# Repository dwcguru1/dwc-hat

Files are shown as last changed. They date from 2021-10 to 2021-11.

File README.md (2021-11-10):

# Rasperry Pi - DWC HAT

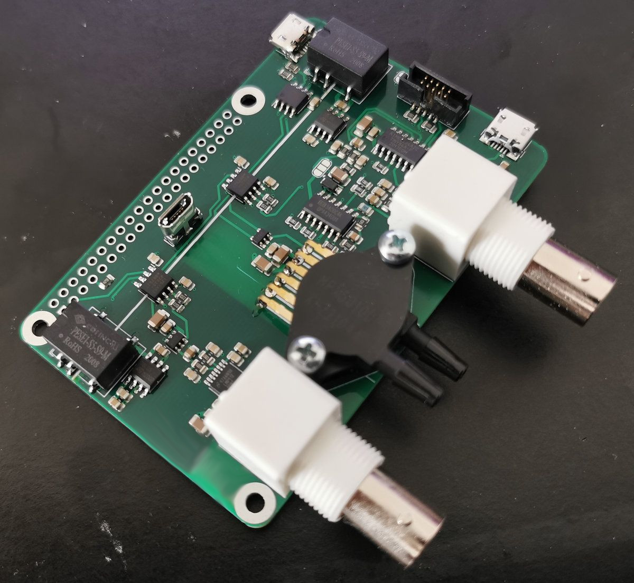
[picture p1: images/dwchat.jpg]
DWC-Hat


Picture above shows V3.0 - New version has some changes (e.g. pinheaders for I2C and 1-wire):

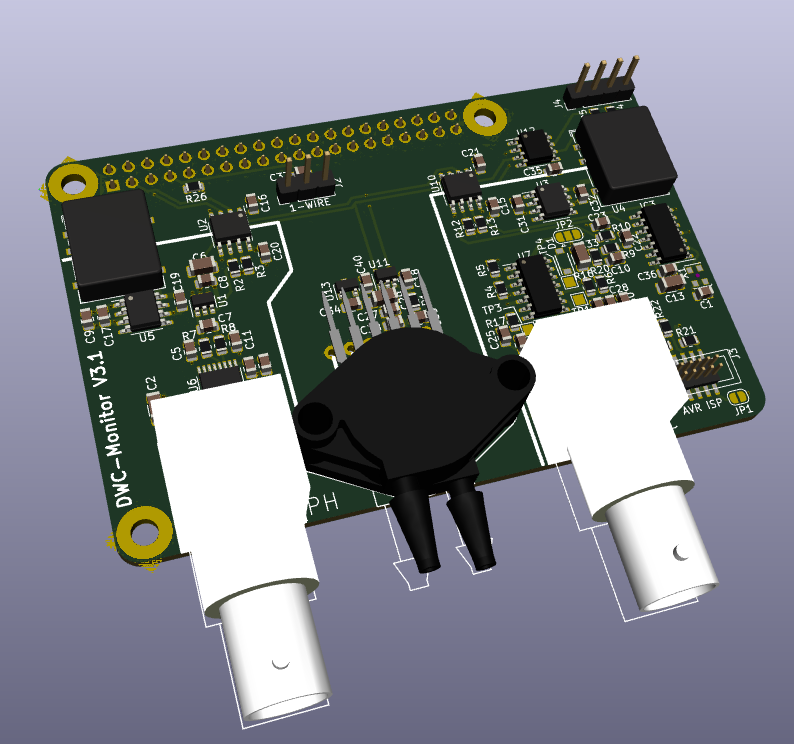
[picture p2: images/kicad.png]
DWC-Hat V3.1


The DWC Hat does following:

- PH measurement (DWC)
- EC measurement (DWC)
- Temperature measurement and correction (DWC)
- Pressure* measurement for water level monitoring (DWC)
- Temperature and humidity measurement of air

*: Everything except the pressure sensing works as expected. It works electrically, but there would be needed a much more sophisticated temperature compensation. To sum it up: It never worked well.

## Raspberry prerequisites

Use `raspi-config` to enable I2C and 1-Wire.

There is a special quirk needed for getting the I2C working properly (because the Pi can't do clock-stretching):

In `/boot/config.txt`:

```
# Uncomment some or all of these to enable the optional hardware interfaces
dtparam=i2c_baudrate=10000
```

It hurts a bit to reduce the I2C rate to 10kHz - but it doesn't really matter :shrug:

Also, the 1-wire pin needs to be configured:
```
# select 1-wire pin
dtoverlay=w1-gpio,gpiopin=4,pullup=on
```

## I2C and 1-wire Devices

There are four I2C and one 1-wire device.

### I2C

```
i2cdetect -y 1:

     0  1  2  3  4  5  6  7  8  9  a  b  c  d  e  f
00:          -- -- -- -- -- -- -- -- -- -- -- -- -- 
10: 10 -- -- -- -- -- -- -- -- -- -- -- -- -- -- -- 
20: -- -- -- -- -- -- -- -- -- -- -- -- -- -- -- -- 
30: -- -- -- -- -- -- -- -- -- -- -- -- -- -- -- -- 
40: 40 -- -- -- -- -- -- -- -- -- -- -- -- 4d -- -- 
50: -- -- -- -- -- -- -- -- -- -- -- -- -- -- -- -- 
60: -- -- -- -- -- -- -- -- -- -- 6a -- -- -- -- -- 
70: -- -- -- -- -- -- -- -- 
```

0x10: EC measurement (fixed by AVR firmware)
0x40: SI7021 temperature and humidity sensor
0x4d: MPX2050DP pressure sensor (ADC MCP3221)
0x6a: PH measurement (ADC MCP3421)

The addresses can differ (e.g. the ADC used in the PH measurement could be either of 0x68 to 0x6f). 

Please check the datasheets of the parts mentioned above and/or `i2cdetect` for the address of your part.

The values are inserted into the `config.ini`:
```
[i2c]
# i2c address of EC measuring (always 0x10)
i2c_ec = 0x10

# i2c address of PH measuring
i2c_ph = 0x6a

# i2c address of MPX2050DP
i2c_pressure = 0x4d

# i2c address of SI7021
i2c_ht = 0x40
```

# 1-Wire

After connecting the 1-wire sensor, there should appear a new device at `/sys/bus/w1/devices/`. 

Add the name to the `config.ini`:

```
[1wire]
ds18b20 = "28-0120625ed8f9"
```

## AVR firmware

The EC-measuring part uses an AVR. Before doing measurements, it needs to be flashed with the firmware.

The ISP connector is 2x10 with 1.27mm pitch. The pinout is compatible to the USBASP.

Also the Makefile expects the USBASP as programmer.

For compilation, you'll need:

```
sudo apt install gcc-avr avrdude avr-libc
```

After that, first initialize the AVR-flags once with:
```
make fuse
```

Afterwards you can compile and flash the AVR with:
```
make
make flash
```

Now, it should be ready to go :slight_smile:

## Calibration

There are two parts that need calibration. (See usage how to get the raw-values).

### PH calibration

PH calibration is done by setting up two reference solutions with PH of 4.01 and 6.86.

After measuring the raw-values, insert them into the `config.ini`:
```
[ph]
# measured PH (raw values)
PH_401 =  13010.0
PH_686 =  2400.0
```

### EC calibration

For calibrating the EC part, two resistors are needed.

They are simply connected to the BNC jack for the EC probe (without the probe) and the raw-values measured by the EC measuring circuit is used for calculating the EC.

The resistors are  390R and 1k.

The values have to be inserted into the `config.ini`:
```
[ec]
# measured EC (raw values)
EC_ADC_390R = 439.0
EC_ADC_1K = 208.0
```

## Usage

By default, the python code does a single measurement and transmitts the date to InfluxDB.

To run it in a loop simply start it in a `screen` session with:
```
 while ((1)); do python3 read.py | tee -a measurements.log ; sleep 1; done

time=1635402997671, ec_raw=243.3764705882353, ec=1345.546146, ph_raw=6772, ph=5.685617, temp=20.875000, pressure_raw=122.5625, pressure_comp=44.20985378262856, humidity=68.68032836914062, airtemp=22.873859863281247
...
```

### Grafana and InfluxDB

Follow any tutorial for installing InfluxDB and Grafana.

Default Database, User, Password is in the `config.ini`.

Make sure to configure the timezone right on the Raspi.

## TODO

There are some things I would like to improve:

- STM32 (M4) for EC measurement. Use internal DAC for DDS sine generation and FIR band pass. This would reduce the parts needed by a lot. Also would improve resolution (12Bit ADC instead of 10Bit ADC).
- Better pt1000 based temperature sensor for DWC. DS18B20 digitizes too coarse what affects temperature compensation of EC negatively.
- Replace the pressure sensing with something else better working. E.g. capacitive sensing with conductive strips glued on the outside of the DWC bin or something else ...

## Disclaimer

Use everything on your own risk!

The project is at it is and if I don't need something else, I won't touch it ever again.

Feel free to do with it whatever you like :slight_smile:

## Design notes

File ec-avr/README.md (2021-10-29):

## compiling the code

For compiling and flashing, you need:
```
sudo apt install gcc-avr avr-libc avrdude
```

After compile with:
```
make
```

If you are using a new AVR, you first have to flash the fuse for the correct oscillator settings:
```
make fuse
```

Afterwards, flash the `.hex`-file.

```
make flash
```

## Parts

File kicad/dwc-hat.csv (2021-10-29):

Reference | Value | Footprint | Datasheet | Distributor | Manufacturer | OrderNr
P1 | BNC | myfootprints:BNC_UG_1094W1 |  | D | 1-1337543-0 | A97553-ND
C12 | 100n | Capacitor_SMD:C_0805_2012Metric
P4 | BNC | myfootprints:BNC_UG_1094W1 |  | D | 1-1337543-0 | A97553-ND
R11 | 3.3k | Resistor_SMD:R_0805_2012Metric
D1 | BAT54T1G | Diodes_SMD:SOD-123 |  | D | BAT54T1G | BAT54T1GOSDKR-ND
C33 | 10µ | Capacitor_SMD:C_1206_3216Metric
R20 | 10k | Resistor_SMD:R_0805_2012Metric
U7 | OPA4340 | Package_SO:SO-14_3.9x8.65mm_P1.27mm | http://www.ti.com/lit/ds/symlink/tl071.pdf | D | OPA4340UA/2K5 | 296-26286-1-ND
R14 | 5.1k | Resistor_SMD:R_0805_2012Metric
R15 | 20k | Resistor_SMD:R_0805_2012Metric
C25 | 33n | Capacitor_SMD:C_0805_2012Metric
C24 | 22n | Capacitor_SMD:C_0805_2012Metric
R17 | 8.2k | Resistor_SMD:R_0805_2012Metric
IC3 | ATTINY84A-SS | Package_SO:SO-14_3.9x8.65mm_P1.27mm |  | D | ATTINY84A-SSF | ATTINY84A-SSF-ND
R22 | 10k | Resistor_SMD:R_0805_2012Metric
C32 | 100n/25V | Capacitor_SMD:C_0805_2012Metric
C31 | 100n | Capacitor_SMD:C_0805_2012Metric
C36 | 100n | Capacitor_SMD:C_0805_2012Metric
U6 | LMP91200 | Package_SO:TSSOP-16_4.4x5mm_P0.65mm |  | D | LMP91200MT/NOPB | LMP91200MT/NOPB-ND
U10 | ADUM1251 | Package_SO:SOIC-8_3.9x4.9mm_P1.27mm |  | D | ADUM1251ARZ-RL7 | ADUM1251ARZ-RL7CT-ND
R13 | 2k2 | Resistor_SMD:R_0805_2012Metric
R12 | 2k2 | Resistor_SMD:R_0805_2012Metric
J3 | Conn_02x05_Odd_Even | myfootprints:PinHeader_IDC_2x05_P1.27mm_Vertical_SMD | ~ | D | 3221-10-0300-00 | 1175-1735-ND
JP1 | Jumper_NO_Small | Jumper:SolderJumper-2_P1.3mm_Open_RoundedPad1.0x1.5mm | ~ | -
NT1 | Net-Tie_2 | NetTie:NetTie-2_SMD_Pad0.5mm | ~ | -
NT2 | Net-Tie_2 | NetTie:NetTie-2_SMD_Pad0.5mm | ~ | -
U1 | MCP3421 | Package_TO_SOT_SMD:SOT-23-6 |  | D | MCP3421A2T-E/CH | MCP3421A2T-E/CHCT-ND
U2 | ADUM1251 | Package_SO:SOIC-8_3.9x4.9mm_P1.27mm |  | D | ADUM1251ARZ-RL7 | ADUM1251ARZ-RL7CT-ND
R3 | 2k2 | Resistor_SMD:R_0805_2012Metric
R2 | 2k2 | Resistor_SMD:R_0805_2012Metric
C2 | 10µ | Capacitor_SMD:C_1206_3216Metric | ~
C3 | 1µ | Capacitor_SMD:C_0805_2012Metric | ~
C4 | 100n | Capacitor_SMD:C_0805_2012Metric | ~
C6 | 10µ | Capacitor_SMD:C_1206_3216Metric | ~
C8 | 100n | Capacitor_SMD:C_0805_2012Metric | ~
C9 | 1µ | Capacitor_SMD:C_0805_2012Metric | ~
C13 | 10µ | Capacitor_SMD:C_1206_3216Metric | ~
J1 | Raspberry Pi GPIO | Connector_PinSocket_2.54mm:PinSocket_2x20_P2.54mm_Vertical |  | D | ESQ-120-24-T-D | SAM15592-ND
C14 | 1µ | Capacitor_SMD:C_0805_2012Metric | ~
U4 | 0509 | myfootprints:Converter_DCDC_SMD |  | D | PESE1-S5-S9-M | 102-6308-ND
U3 | L78L05_SO8 | Package_SO:SOIC-8_3.9x4.9mm_P1.27mm | http://www.st.com/content/ccc/resource/technical/document/datasheet/15/55/e5/aa/23/5b/43/fd/CD00000446.pdf/files/CD00000446.pdf/jcr:content/translations/en.CD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 | D | L78L05CD13TR | 497-7267-1-ND
C19 | 100n/25V | Capacitor_SMD:C_0805_2012Metric
C17 | 100n | Capacitor_SMD:C_0805_2012Metric
U8 | 0509 | myfootprints:Converter_DCDC_SMD |  | D | PESE1-S5-S9-M | 102-6308-ND
U5 | L78L05_SO8 | Package_SO:SOIC-8_3.9x4.9mm_P1.27mm | http://www.st.com/content/ccc/resource/technical/document/datasheet/15/55/e5/aa/23/5b/43/fd/CD00000446.pdf/files/CD00000446.pdf/jcr:content/translations/en.CD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 | D | L78L05CD13TR | 497-7267-1-ND
R4 | 100k | Resistor_SMD:R_0805_2012Metric | ~
R5 | 100k | Resistor_SMD:R_0805_2012Metric | ~
R19 | 4.7k | Resistor_SMD:R_0805_2012Metric
R18 | 4.7k | Resistor_SMD:R_0805_2012Metric
C30 | 100n | Capacitor_SMD:C_0805_2012Metric
C28 | 100n | Capacitor_SMD:C_0805_2012Metric
C26 | 1µ | Capacitor_SMD:C_0805_2012Metric
R16 | 100k | Resistor_SMD:R_0805_2012Metric
R6 | 100k | Resistor_SMD:R_0805_2012Metric
C20 | 100n | Capacitor_SMD:C_0805_2012Metric | ~
C21 | 100n | Capacitor_SMD:C_0805_2012Metric | ~
C15 | 100n | Capacitor_SMD:C_0805_2012Metric | ~
C16 | 100n | Capacitor_SMD:C_0805_2012Metric | ~
R7 | 1k | Resistor_SMD:R_0805_2012Metric
R8 | 1k | Resistor_SMD:R_0805_2012Metric
C7 | 47n | Capacitor_SMD:C_0805_2012Metric
C5 | 100n | Capacitor_SMD:C_0805_2012Metric
C11 | 100n | Capacitor_SMD:C_0805_2012Metric
JP2 | Jumper_3_Open | Jumper:SolderJumper-3_P1.3mm_Open_RoundedPad1.0x1.5mm | ~ | -
R9 | 1k | Resistor_SMD:R_0805_2012Metric
R10 | 1k | Resistor_SMD:R_0805_2012Metric
C22 | 47n | Capacitor_SMD:C_0805_2012Metric
C10 | 100n | Capacitor_SMD:C_0805_2012Metric
C23 | 100n | Capacitor_SMD:C_0805_2012Metric
R21 | 1k | Resistor_SMD:R_0805_2012Metric
R23 | 1k | Resistor_SMD:R_0805_2012Metric
U9 | MPX5010DP | myfootprints:MPX5010DP |  | D | MPX5010DP | MPX5010DP-ND
C29 | 10µ | Capacitor_SMD:C_1206_3216Metric | ~
C34 | 100n | Capacitor_SMD:C_0805_2012Metric | ~
U11 | MCP3221 | Package_TO_SOT_SMD:SOT-23-5 |  | D | MCP3221A5T-I/OT | MCP3221A5T-I/OTCT-ND
U12 | PCA9515 | Package_SO:SO-8_3.9x4.9mm_P1.27mm |  | D | PI6ULS5V9515AWEX | PI6ULS5V9515AWEXCT-ND
R25 | 2k2 | Resistor_SMD:R_0805_2012Metric
R24 | 2k2 | Resistor_SMD:R_0805_2012Metric
C35 | 100n | Capacitor_SMD:C_0805_2012Metric | ~
R26 | 4.7k | Resistor_SMD:R_0805_2012Metric
C37 | 1µ | Capacitor_SMD:C_0805_2012Metric
C39 | 470p | Capacitor_SMD:C_0805_2012Metric
C27 | 1µ | Capacitor_SMD:C_0805_2012Metric
C38 | 100n | Capacitor_SMD:C_0805_2012Metric
J4 | Conn_01x04 | Connector_PinHeader_2.54mm:PinHeader_1x04_P2.54mm_Vertical | ~
J2 | Conn_01x03 | Connector_PinHeader_2.54mm:PinHeader_1x03_P2.54mm_Vertical | ~
X1 | 8MHz | Oscillator:Oscillator_SMD_EuroQuartz_XO32-4Pin_3.2x2.5mm | http://cdn-reichelt.de/documents/datenblatt/B400/XO32.pdf
C1 | 100n | Capacitor_SMD:C_0805_2012Metric | ~
TP2 | TestPoint | TestPoint:TestPoint_Pad_1.5x1.5mm | ~
TP3 | TestPoint | TestPoint:TestPoint_Pad_1.5x1.5mm | ~
TP1 | TestPoint | TestPoint:TestPoint_Pad_1.5x1.5mm | ~
TP4 | TestPoint | TestPoint:TestPoint_Pad_1.5x1.5mm | ~
R1 | 1k | Resistor_SMD:R_0805_2012Metric
C18 | 100n | Capacitor_SMD:C_0805_2012Metric
U13 | MCP1541-TT | Package_TO_SOT_SMD:SOT-23 | http://ww1.microchip.com/downloads/en/devicedoc/21653b.pdf
C40 | 1µ | Capacitor_SMD:C_0805_2012Metric

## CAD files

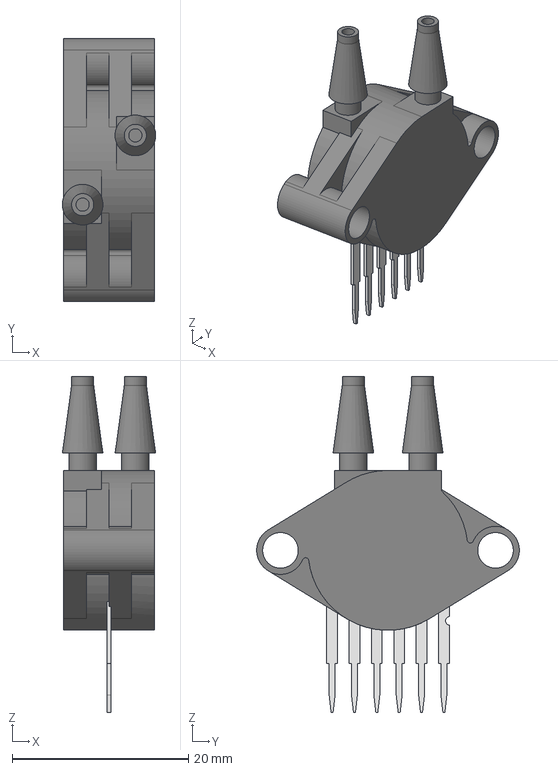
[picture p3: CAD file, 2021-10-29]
kicad/3d/NXP_-_MPX5010DP.step
10.6 x 29.8 x 38.2 mm

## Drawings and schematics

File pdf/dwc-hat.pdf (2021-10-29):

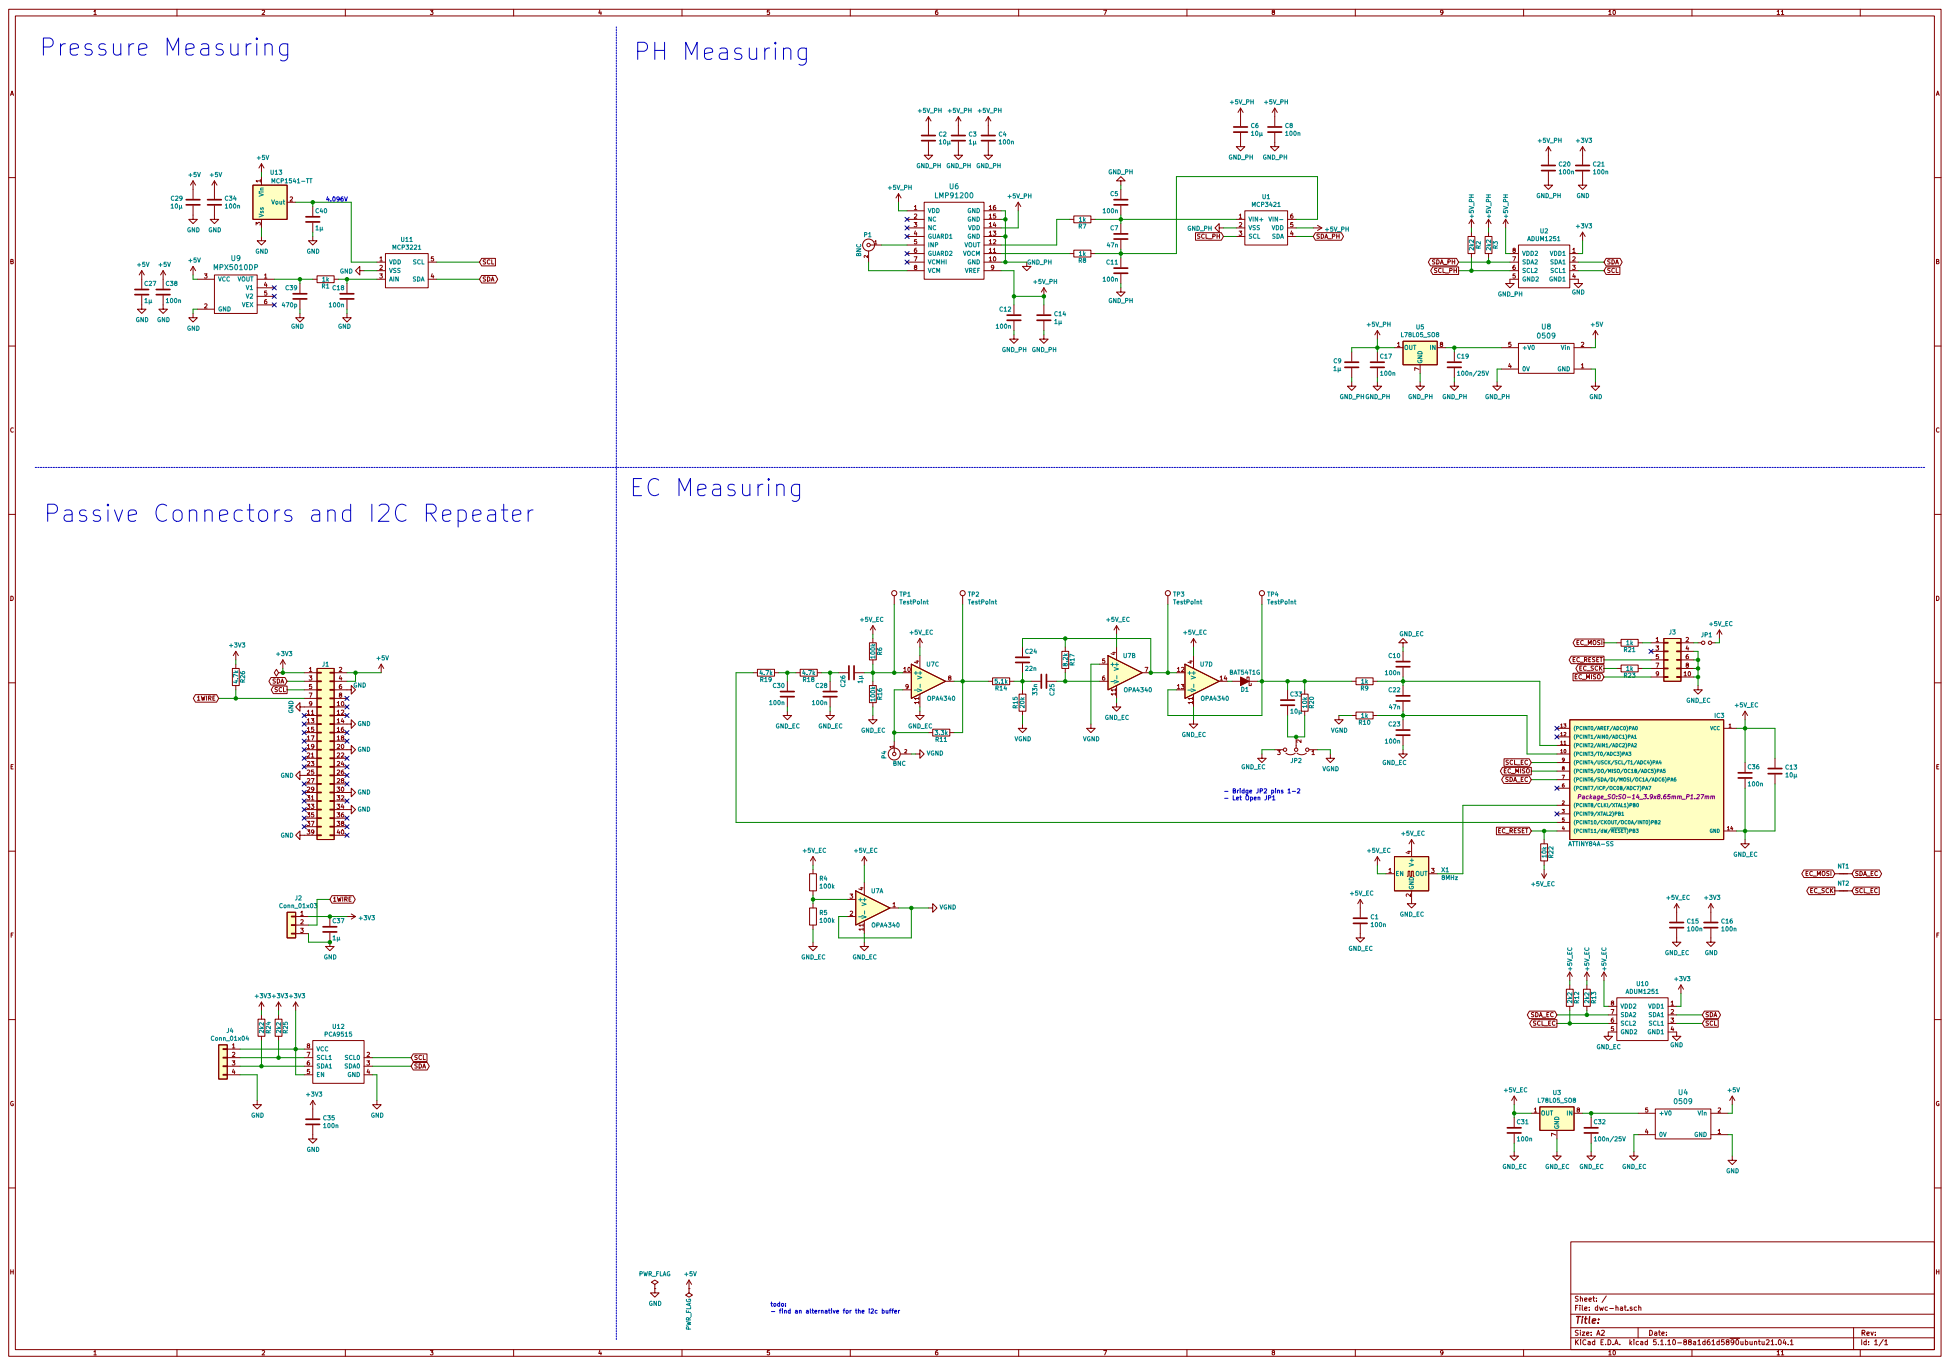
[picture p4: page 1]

1 Vout 2 Vss 3 U13 MCP1541-TT GND
10µ GND

Passive Connectors and I2C Repeater

todo: - find an alternative for the i2c buffer

Id: 1/1 Title: File: dwc-hat.sch Sheet: /

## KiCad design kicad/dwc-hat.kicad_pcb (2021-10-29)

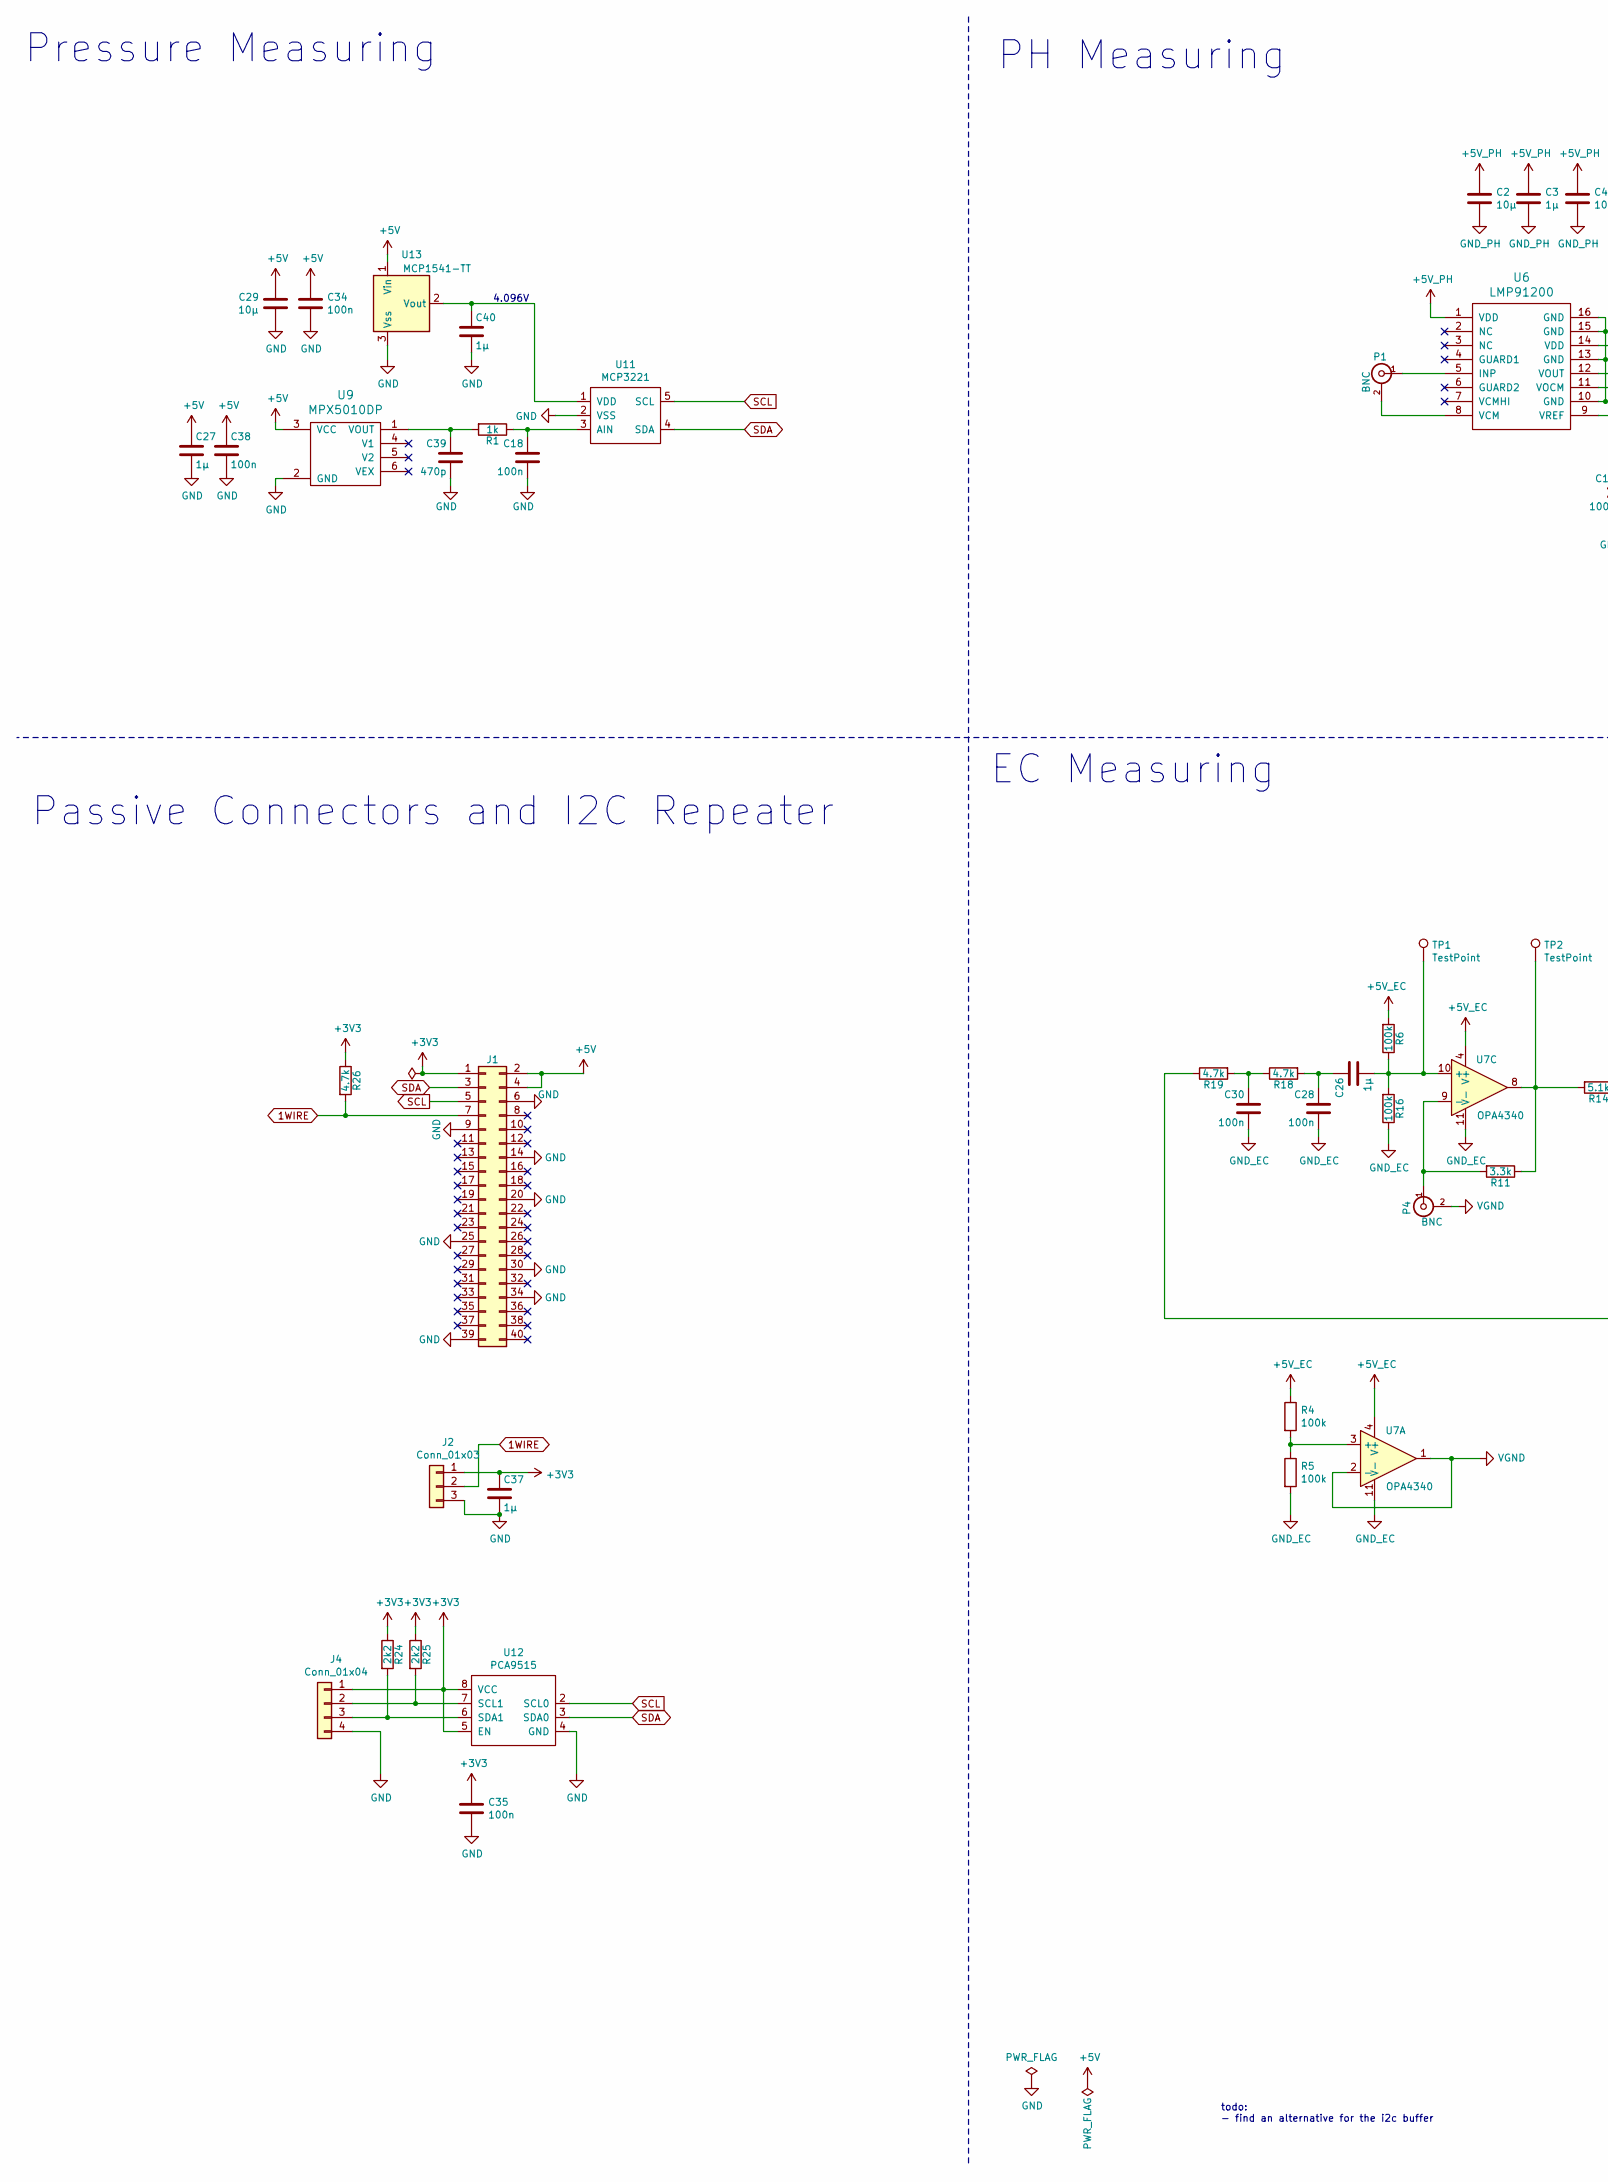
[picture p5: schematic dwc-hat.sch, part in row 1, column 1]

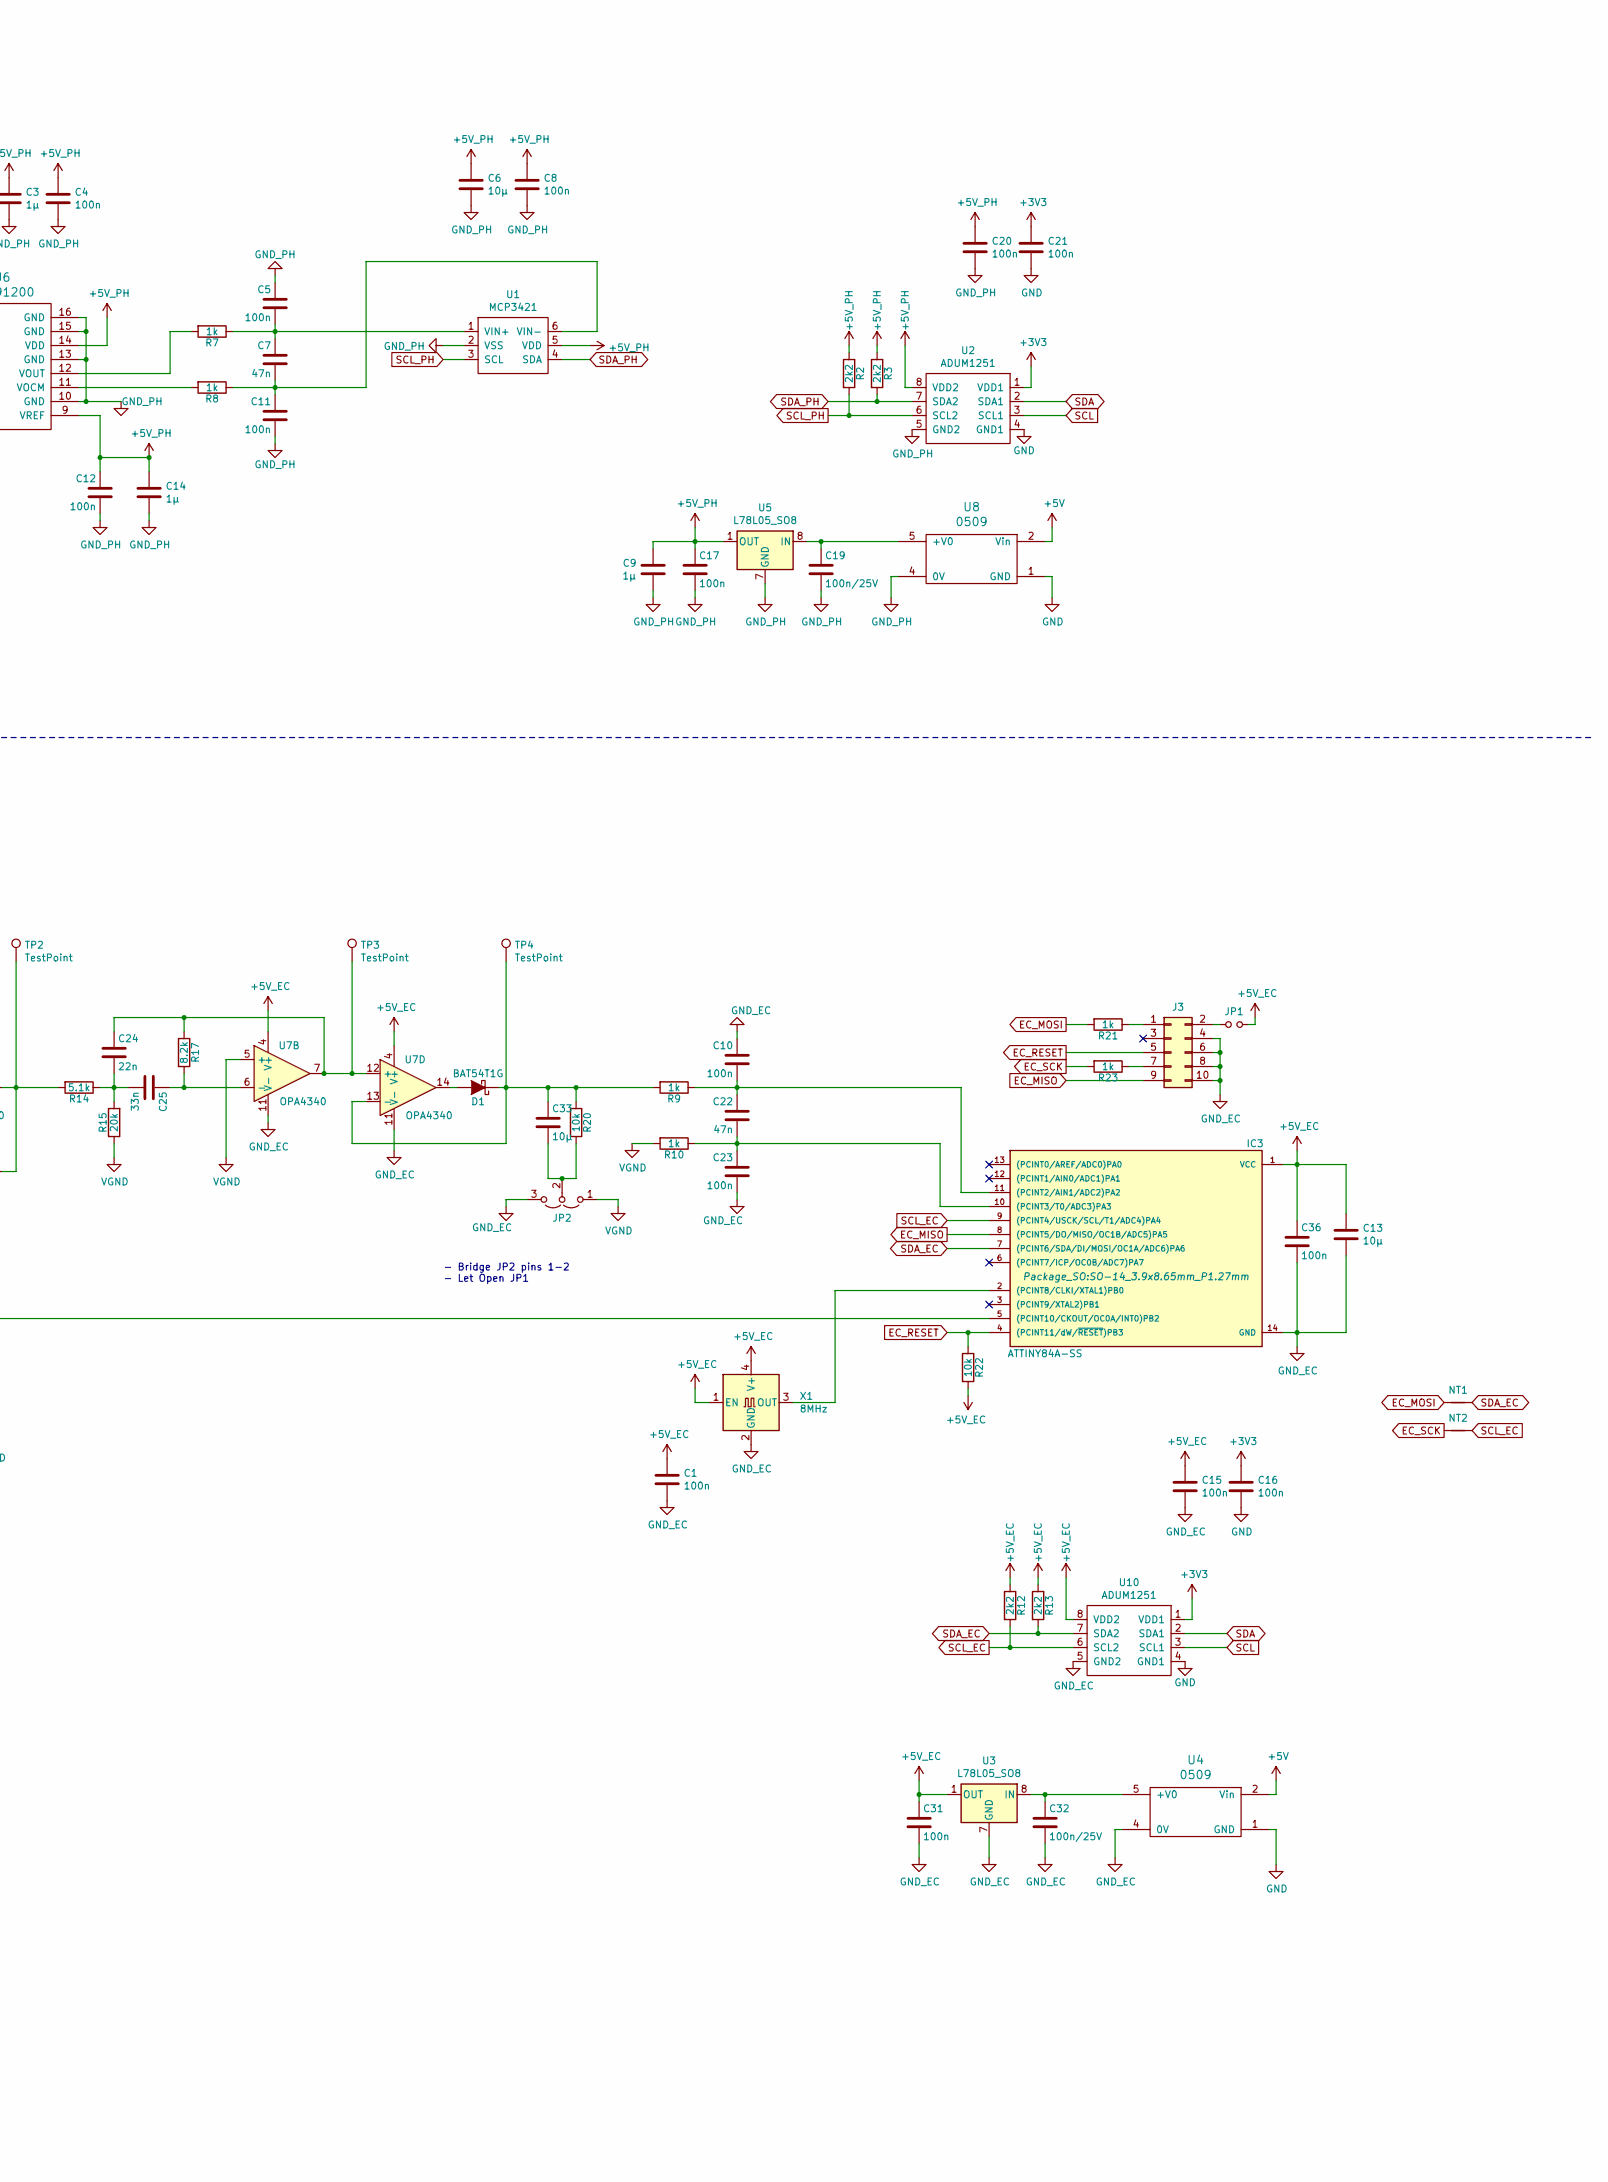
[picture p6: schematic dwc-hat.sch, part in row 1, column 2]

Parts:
C1, C4, C5, C8, C10, C11, C12, C15, C16, C17, C18, C20, C21, C23, C28, C30, C31, C34, C35, C36, C38: 100n; C_0805_2012Metric
C2, C6, C13, C29, C33: 10µ; C_1206_3216Metric
C3, C9, C14, C26, C27, C37, C40: 1µ; C_0805_2012Metric
C7, C22: 47n; C_0805_2012Metric
C19, C32: 100n/25V; C_0805_2012Metric
C24: 22n; C_0805_2012Metric
C25: 33n; C_0805_2012Metric
C39: 470p; C_0805_2012Metric
D1: BAT54T1G; SOD-123
IC3: ATTINY84A-SS; SO-14_3.9x8.65mm_P1.27mm
J1: Raspberry Pi GPIO; PinSocket_2x20_P2.54mm_Vertical
J2: Conn_01x03; PinHeader_1x03_P2.54mm_Vertical
J3: Conn_02x05_Odd_Even; PinHeader_IDC_2x05_P1.27mm_Vertical_SMD
J4: Conn_01x04; PinHeader_1x04_P2.54mm_Vertical
JP1: Jumper_NO_Small; SolderJumper-2_P1.3mm_Open_RoundedPad1.0x1.5mm
JP2: Jumper_3_Open; SolderJumper-3_P1.3mm_Open_RoundedPad1.0x1.5mm
NT1, NT2: Net-Tie_2; NetTie-2_SMD_Pad0.5mm
P1, P4: BNC; BNC_UG_1094W1
R1, R7, R8, R9, R10, R21, R23: 1k; R_0805_2012Metric
R2, R3, R12, R13, R24, R25: 2k2; R_0805_2012Metric
R4, R5, R6, R16: 100k; R_0805_2012Metric
R11: 3.3k; R_0805_2012Metric
R14: 5.1k; R_0805_2012Metric
R15: 20k; R_0805_2012Metric
R17: 8.2k; R_0805_2012Metric
R18, R19, R26: 4.7k; R_0805_2012Metric
R20, R22: 10k; R_0805_2012Metric
TP1, TP2, TP3, TP4: TestPoint; TestPoint_Pad_1.5x1.5mm
U1: MCP3421; SOT-23-6
U2, U10: ADUM1251; SOIC-8_3.9x4.9mm_P1.27mm
U3, U5: L78L05_SO8; SOIC-8_3.9x4.9mm_P1.27mm
U4, U8: 0509; Converter_DCDC_SMD
U6: LMP91200; TSSOP-16_4.4x5mm_P0.65mm
U7: OPA4340; SO-14_3.9x8.65mm_P1.27mm
U9: MPX5010DP
U11: MCP3221; SOT-23-5
U12: PCA9515; SO-8_3.9x4.9mm_P1.27mm
U13: MCP1541-TT; SOT-23
X1: 8MHz; Oscillator_SMD_EuroQuartz_XO32-4Pin_3.2x2.5mm

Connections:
1WIRE: J1.7, J2.2, R26.2
+3V3: C16.1, C21.1, C35.1, C37.1, J1.1, J2.1, J4.1, R24.1, R25.1, R26.1, U2.1 (VDD1), U10.1 (VDD1), U12.5 (EN), U12.8 (VCC)
+5V: C27.1, C29.1, C34.1, C38.1, J1.2, J1.4, U4.2 (Vin), U8.2 (Vin), U9.3 (VCC), U13.1 (Vin)
+5V_EC: C1.1, C13.1, C15.1, C31.1, C36.1, IC3.1 (VCC), JP1.2, R4.1, R6.2, R12.1, R13.1, R22.2, U3.1 (OUT), U7.4 (V+), U10.8 (VDD2), X1.1 (EN), X1.4 (V+)
+5V_PH: C2.1, C3.1, C4.1, C6.1, C8.1, C9.1, C12.1, C14.1, C17.1, C20.1, R2.1, R3.1, U1.5 (VDD), U2.8 (VDD2), U5.1 (OUT), U6.1 (VDD), U6.9 (VREF), U6.14 (VDD)
EC_MISO: IC3.8 ((PCINT5/DO/MISO/OC1B/ADC5)PA5), J3.9
EC_MOSI: NT1.1, R21.2
EC_RESET: IC3.4 ((PCINT11/dW/~RESET~)PB3), J3.5, R22.1
EC_SCK: NT2.1, R23.2
GND: C16.2, C18.2, C21.2, C27.2, C29.2, C34.2, C35.2, C37.2, C38.2, C39.2, C40.2, J1.6, J1.9, J1.14, J1.20, J1.25, J1.30, J1.34, J1.39, J2.3, J4.4, U2.4 (GND1), U4.1 (GND), U8.1 (GND), U9.2 (GND), U10.4 (GND1), U11.2 (VSS), U12.4 (GND), U13.3 (Vss)
GND_EC: C1.2, C10.1, C13.2, C15.2, C23.2, C28.2, C30.2, C31.2, C32.2, C36.2, IC3.14 (GND), J3.4, J3.6, J3.8, J3.10, JP2.3 (B), R5.2, R16.1, U3.2 (GND), U3.3 (GND), U3.6 (GND), U3.7 (GND), U4.4 (0V), U7.11 (V-), U10.5 (GND2), X1.2 (GND)
GND_PH: C2.2, C3.2, C4.2, C5.1, C6.2, C8.2, C9.2, C11.2, C12.2, C14.2, C17.2, C19.2, C20.2, U1.2 (VSS), U2.5 (GND2), U5.2 (GND), U5.3 (GND), U5.6 (GND), U5.7 (GND), U6.10 (GND), U6.13 (GND), U6.15 (GND), U6.16 (GND), U8.4 (0V)
unnamed: C5.2, C7.1, R7.1, U1.1 (VIN+)
unnamed: C10.2, C22.1, IC3.11 ((PCINT2/AIN1/ADC2)PA2), R9.1
unnamed: C7.2, C11.1, R8.1, U1.6 (VIN-)
unnamed: C18.1, R1.1, U11.3 (AIN)
unnamed: C19.1, U5.8 (IN), U8.5 (+V0)
unnamed: C22.2, C23.1, IC3.10 ((PCINT3/T0/ADC3)PA3), R10.1
unnamed: C24.1, R17.1, TP3.1, U7.7, U7.12 (+)
unnamed: C24.2, C25.2, R14.1, R15.2
unnamed: C25.1, R17.2, U7.6 (-)
unnamed: C26.1, C28.1, R18.2
unnamed: C26.2, R6.1, R16.2, TP1.1, U7.10 (+)
unnamed: C30.1, R18.1, R19.2
unnamed: C32.1, U3.8 (IN), U4.5 (+V0)
unnamed: C33.1, D1.1 (K), R9.2, R20.1, TP4.1, U7.13 (-)
unnamed: C33.2, JP2.2 (C), R20.2
unnamed: C39.1, R1.2, U9.1 (VOUT)
unnamed: C40.1, U11.1 (VDD), U13.2 (Vout)
unnamed: D1.2 (A), U7.14
unnamed: IC3.2 ((PCINT8/CLKI/XTAL1)PB0), X1.3 (OUT)
unnamed: IC3.5 ((PCINT10/CKOUT/OC0A/INT0)PB2), R19.1
unnamed: J3.1, R21.1
unnamed: J3.2, JP1.1
unnamed: J3.7, R23.1
unnamed: J4.2, R25.2, U12.7 (SCL1)
unnamed: J4.3, R24.2, U12.6 (SDA1)
unnamed: P1.1 (In), U6.5 (INP)
unnamed: P1.2 (Ext), U6.8 (VCM)
unnamed: P4.1 (In), R11.2, U7.9 (-)
unnamed: R4.2, R5.1, U7.3 (+)
unnamed: R7.2, U6.12 (VOUT)
unnamed: R8.2, U6.11 (VOCM)
unnamed: R11.1, R14.2, TP2.1, U7.8
SCL: J1.5, U2.3 (SCL1), U10.3 (SCL1), U11.5 (SCL), U12.2 (SCL0)
SCL_EC: IC3.9 ((PCINT4/USCK/SCL/T1/ADC4)PA4), NT2.2, R12.2, U10.6 (SCL2)
SCL_PH: R2.2, U1.3 (SCL), U2.6 (SCL2)
SDA: J1.3, U2.2 (SDA1), U10.2 (SDA1), U11.4 (SDA), U12.3 (SDA0)
SDA_EC: IC3.7 ((PCINT6/SDA/DI/MOSI/OC1A/ADC6)PA6), NT1.2, R13.2, U10.7 (SDA2)
SDA_PH: R3.2, U1.4 (SDA), U2.7 (SDA2)
VGND: JP2.1 (A), P4.2 (Ext), R10.2, R15.1, U7.1, U7.2 (-), U7.5 (+)

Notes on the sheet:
todo: - find an alternative for the i2c buffer
EC Measuring
PH Measuring
Pressure Measuring
Passive Connectors and I2C Repeater
- Bridge JP2 pins 1-2 - Let Open JP1
4.096V

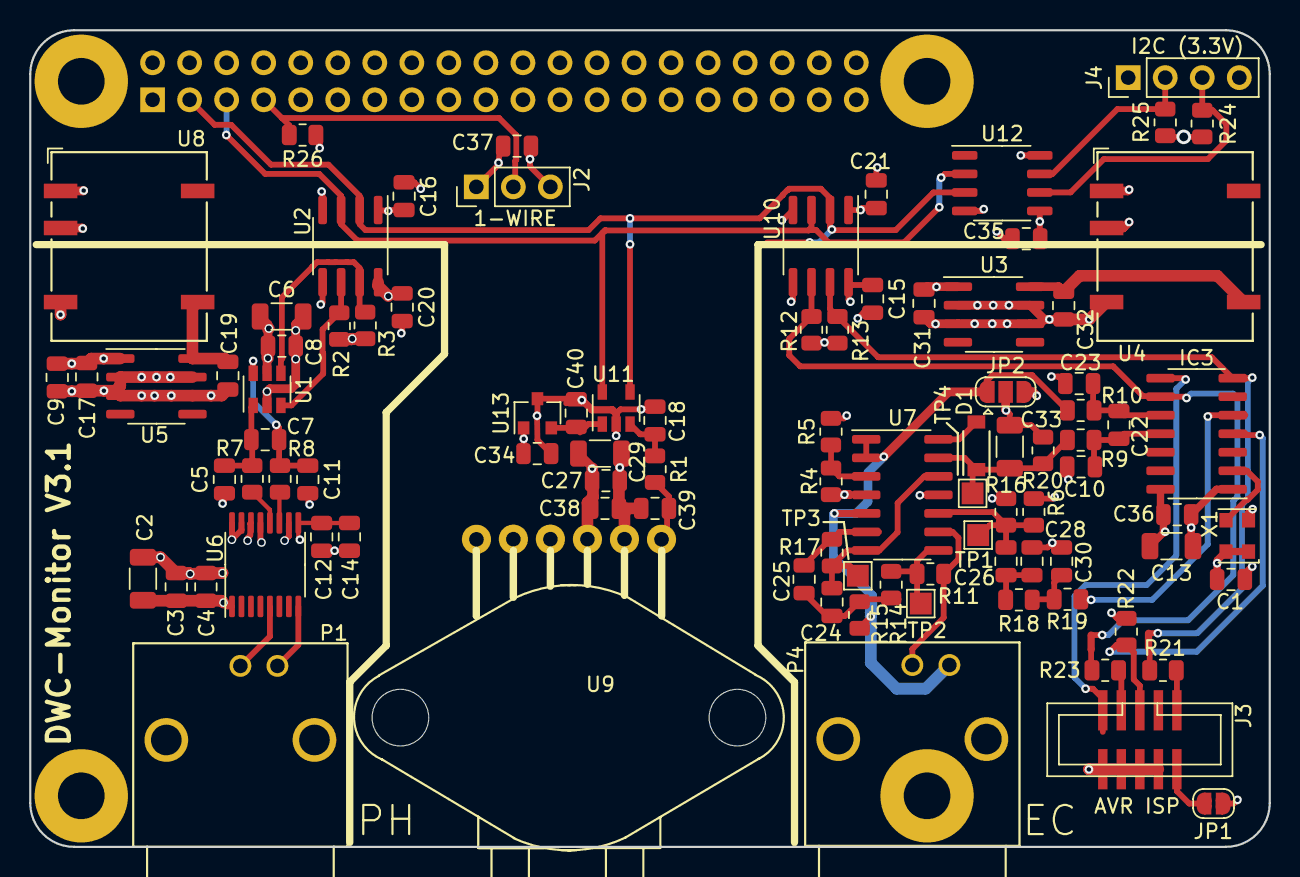
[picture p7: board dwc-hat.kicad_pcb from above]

Board: 4 copper layers, 85.0 x 56.0 mm, 96 parts (1 on the bottom side), 51 nets.

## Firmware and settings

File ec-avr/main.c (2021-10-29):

/*****************************************************************************
*
* Atmel Corporation
*
* File              : USI_TWI_Slave.c
* Compiler          : IAR EWAAVR 2.28a/3.10a
* Revision          : $Revision: 1.7 $
* Date              : $Date: 26. mai 2004 11:35:34 $
* Updated by        : $Author: ltwa $
*
* Support mail      : avr@atmel.com
*
* Supported devices : All device with USI module can be used.
*                     The example is written for the ATmega169, ATtiny26 & ATtiny2313
*
* AppNote           : AVR312 - Using the USI module as a TWI slave
*
* Description       : Example showing how to use the USI_TWI drivers;
*                     Loops back received data.
*
* Changes for WinAVR by Frank Jonischkies, fjonisch@gmx.de, 11.08.2005
*
****************************************************************************/

#include <avr/pgmspace.h>
#include <util/delay.h>

#include <avr/io.h>
#include <avr/interrupt.h>
#include "USI_TWI_Slave.h"

// gcc doesn't know this and ledger's SDK cannot be compiled with Werror!
//#pragma GCC diagnostic error "-Werror"
#pragma GCC diagnostic error "-Wpedantic"
#pragma GCC diagnostic error "-Wall"
#pragma GCC diagnostic error "-Wextra"

const int sinewave_length = 256;
const unsigned char sinewave_data[] PROGMEM = {
    0x80, 0x83, 0x86, 0x89, 0x8c, 0x8f, 0x92, 0x95, 0x98, 0x9c, 0x9f, 0xa2, 0xa5, 0xa8, 0xab, 0xae,
    0xb0, 0xb3, 0xb6, 0xb9, 0xbc, 0xbf, 0xc1, 0xc4, 0xc7, 0xc9, 0xcc, 0xce, 0xd1, 0xd3, 0xd5, 0xd8,
    0xda, 0xdc, 0xde, 0xe0, 0xe2, 0xe4, 0xe6, 0xe8, 0xea, 0xec, 0xed, 0xef, 0xf0, 0xf2, 0xf3, 0xf5,
    0xf6, 0xf7, 0xf8, 0xf9, 0xfa, 0xfb, 0xfc, 0xfc, 0xfd, 0xfe, 0xfe, 0xff, 0xff, 0xff, 0xff, 0xff,
    0xff, 0xff, 0xff, 0xff, 0xff, 0xff, 0xfe, 0xfe, 0xfd, 0xfc, 0xfc, 0xfb, 0xfa, 0xf9, 0xf8, 0xf7,
    0xf6, 0xf5, 0xf3, 0xf2, 0xf0, 0xef, 0xed, 0xec, 0xea, 0xe8, 0xe6, 0xe4, 0xe2, 0xe0, 0xde, 0xdc,
    0xda, 0xd8, 0xd5, 0xd3, 0xd1, 0xce, 0xcc, 0xc9, 0xc7, 0xc4, 0xc1, 0xbf, 0xbc, 0xb9, 0xb6, 0xb3,
    0xb0, 0xae, 0xab, 0xa8, 0xa5, 0xa2, 0x9f, 0x9c, 0x98, 0x95, 0x92, 0x8f, 0x8c, 0x89, 0x86, 0x83,
    0x80, 0x7c, 0x79, 0x76, 0x73, 0x70, 0x6d, 0x6a, 0x67, 0x63, 0x60, 0x5d, 0x5a, 0x57, 0x54, 0x51,
    0x4f, 0x4c, 0x49, 0x46, 0x43, 0x40, 0x3e, 0x3b, 0x38, 0x36, 0x33, 0x31, 0x2e, 0x2c, 0x2a, 0x27,
    0x25, 0x23, 0x21, 0x1f, 0x1d, 0x1b, 0x19, 0x17, 0x15, 0x13, 0x12, 0x10, 0x0f, 0x0d, 0x0c, 0x0a,
    0x09, 0x08, 0x07, 0x06, 0x05, 0x04, 0x03, 0x03, 0x02, 0x01, 0x01, 0x00, 0x00, 0x00, 0x00, 0x00,
    0x00, 0x00, 0x00, 0x00, 0x00, 0x00, 0x01, 0x01, 0x02, 0x03, 0x03, 0x04, 0x05, 0x06, 0x07, 0x08,
    0x09, 0x0a, 0x0c, 0x0d, 0x0f, 0x10, 0x12, 0x13, 0x15, 0x17, 0x19, 0x1b, 0x1d, 0x1f, 0x21, 0x23,
    0x25, 0x27, 0x2a, 0x2c, 0x2e, 0x31, 0x33, 0x36, 0x38, 0x3b, 0x3e, 0x40, 0x43, 0x46, 0x49, 0x4c,
    0x4f, 0x51, 0x54, 0x57, 0x5a, 0x5d, 0x60, 0x63, 0x67, 0x6a, 0x6d, 0x70, 0x73, 0x76, 0x79, 0x7c};

// 1000*256/(8E6/256)

// with RC-oscillator, timer frequency is more like 33.7kHz
// akku_inkr = (uint32_t) (dds_frequency * 256ll * (1ll<<24ll) / 33700ll);
volatile uint32_t akku_inkr = 0x079D5157;   // dds frequency 1kHz

volatile uint32_t akku = 0x00000000;
volatile uint8_t stop_dds = 0;
volatile uint16_t adc_val = 0;

#define GETINDEX(a) ((a & 0xff000000) >> 24)

volatile uint32_t t1 = 0;

// This is called at SAMPLE_RATE kHz to load the next sample.
ISR(TIM0_OVF_vect)
{
    if (stop_dds)
    {
        OCR0A = 0x80;
        return;
    }

    akku += akku_inkr;
    OCR0A = pgm_read_byte(&sinewave_data[GETINDEX(akku)]);
}

volatile uint8_t reg_position;

void requestEvent()
{
    uint8_t data = 0x00;
    switch (reg_position)
    {
    case 0:
    case 1:
    case 2:
    case 3:
    {
        uint8_t *pakku_inkr = (uint8_t *)&akku_inkr;
        data = pakku_inkr[reg_position];
        break;
    }
    case 4:
        adc_val = ADCW;
        data = adc_val & 0x00ff;
        break;
    case 5:
        data = (adc_val & 0xff00) >> 8;
        break;
    default:
        break;
    }

    usiTwiTransmitByte(data);
    // Increment the reg position on each read, and loop back to zero
    reg_position += 1;
}

void receiveEvent(uint8_t left)
{
    // Sanity-check
    if (left < 1 || left > TWI_RX_BUFFER_SIZE)
    {
        return;
    }

    reg_position = usiTwiReceiveByte();
    left--;
    while (left--)
    {
        // write akkuinkr
        if (reg_position < 4)
        {
            uint8_t *pakku_inkr = (uint8_t *)&akku_inkr;
            pakku_inkr[reg_position] = usiTwiReceiveByte();
        }
        else if (reg_position == 4)
        {
            uint8_t tmp = usiTwiReceiveByte();
            stop_dds = !!(tmp & 0x80);
        }
        reg_position++;
    }
}

void TinyWireS_stop_check()
{
    if (!usi_onReceiverPtr)
    {
        // no onReceive callback, nothing to do...
        return;
    }
    if (!(USISR & (1 << USIPF)))
    {
        // Stop not detected
        return;
    }
    uint8_t amount = usiTwiAmountDataInReceiveBuffer();
    if (amount == 0)
    {
        // no data in buffer
        return;
    }
    usi_onReceiverPtr(amount);
}

int main(void)
{
    //	OSCCAL = 0x47; // Wert mit Programiergerät auslesen und hier einsetzen!

    // Own TWI slave address
    uint8_t TWI_slaveAddress = 0x10; // 7 bit address with R/W bit also: (0x10<<1) = 0x20
    usiTwiSlaveInit(TWI_slaveAddress);
    usi_onReceiverPtr = receiveEvent;
    usi_onRequestPtr = requestEvent;

    // init sine dds
    DDRB |= (1 << PB2);
    TCCR0A = 0xc3;
    TCCR0B = 0x01;
    TIMSK0 = 0x01;
    sei();
    OCR0A = pgm_read_byte(&sinewave_data[GETINDEX(akku)]) >> 2;

    // ADC
    ADCSRA |= (1 << ADPS2) | (1 << ADPS1) | (1 << ADPS0); // Set ADC prescaler to 128 - 125KHz sample rate @ 16MHz

    //ADMUX |= (0 << REFS0); // Set ADC ref to INTERNAL 5v
    //ADMUX |= (1 << ADLAR); // Left adjust ADC result to allow easy 8 bit reading

    DDRA &= ~((1 << PA3) | (1 << PA2));
    PORTA &= ~((1 << PA3) | (1 << PA2));

    ADMUX = 0x10; // VCC Ref, Gain 1x, ADC3 in+, ADC2 in-

    ADCSRA |= (1 << ADATE); // My change.. Tiny free-Running Mode enabled.
    ADCSRA |= (1 << ADEN);  // Enable ADC

    ADCSRA |= (1 << ADSC); // Start A2D Conversions

    //DDRA |= (1 << PA2);
    //PORTA &= ~(1 << PA2);

    // This example is made to work together with the AVR310 USI TWI Master application note. In adition to connecting the TWI
    // pins, also connect PORTB to the LEDS. The code reads a message as a TWI slave and acts according to if it is a
    // general call, or an address call. If it is an address call, then the first byte is considered a command byte and
    // it then responds differently according to the commands.

    // This loop runs forever. If the TWI Transceiver is busy the execution will just continue doing other operations.
    for (;;)
    {
        TinyWireS_stop_check();
    }
}

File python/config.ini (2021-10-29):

[grafana]
user = "grafana"
pass = "grafana"
db   = "home"
host = "127.0.0.1"
port = 8086


[i2c]

# i2cdetect -y 1:
#
#      0  1  2  3  4  5  6  7  8  9  a  b  c  d  e  f
# 00:          -- -- -- -- -- -- -- -- -- -- -- -- -- 
# 10: 10 -- -- -- -- -- -- -- -- -- -- -- -- -- -- -- 
# 20: -- -- -- -- -- -- -- -- -- -- -- -- -- -- -- -- 
# 30: -- -- -- -- -- -- -- -- -- -- -- -- -- -- -- -- 
# 40: 40 -- -- -- -- -- -- -- -- -- -- -- -- 4d -- -- 
# 50: -- -- -- -- -- -- -- -- -- -- -- -- -- -- -- -- 
# 60: -- -- -- -- -- -- -- -- -- -- 6a -- -- -- -- -- 
# 70: -- -- -- -- -- -- -- -- 


# i2c address of EC measuring (always 0x10)
i2c_ec = 0x10

# i2c address of PH measuring
i2c_ph = 0x6a

# i2c address of MPX2050DP
i2c_pressure = 0x4d

# i2c address of SI7021
i2c_ht = 0x40

[1wire]
ds18b20 = "28-0120625ed8f9"

[ph]
# amplifier in adc for PH
PH_GAIN = 4    

[pressure]
# reading of sensor without pressure applied
P_OFS = 72.0


[ec]
# measured EC (raw values)
# resistors give values like measuring a fluid at 25C
EC_ADC_390R = 439.0
EC_ADC_1K = 208.0

# temperature compensation factor commonly used for nutirent solutions
EC_ALPHA = 0.0191

[ph]
# measured PH (raw values)
PH_401 =  13010.0
PH_686 =  2400.0

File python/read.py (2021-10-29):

#!/usr/bin/env python3
import sys
from smbus import SMBus
import struct
import time
import datetime

from influxdb import InfluxDBClient
import configparser

config = configparser.ConfigParser()
config.read("config.ini")

ifuser = config["grafana"]["user"]
ifpass = config["grafana"]["pass"]
ifdb = config["grafana"]["home"]
ifhost = config["grafana"]["host"]
ifport = int(config["grafana"]["port"])

#i2c
#default akku constant 0x079D5157
i2c_ec = int(config["i2c"]["i2c_ec"])
i2c_ph = int(config["i2c"]["i2c_ph"])
i2c_pressure = int(config["i2c"]["i2c_pressure"])
i2c_ht = int(config["i2c"]["i2c_ht"])

# 1Wire 
ds18b20 = config["1wire"]["ds18b20"]

# PH parameter
ph_gain = int(config["ph"]["PH_GAIN"])    # amplifier in adc for PH
ph_lsb = 2.0 * 2.048 / 262144.0
ph_pga = float(ph_gain)

# measured EC
# resistors give values like measuring a fluid at 25C
ec_adc_390R = float(config["ec"]["EC_ADC_390R"])
ec_adc_1k = float(config["ec"]["EC_ADC_1K"])

# temperature compensation factor commonly used for nutirent solutions
ec_alpha = float(config["ec"]["EC_ALPHA"])

# constants EC (do not edit)
EC_390R = 2564.10
EC_1K  = 1000.0

# measured PH 
PH_401 =  float(config["ph"]["PH_401"])
PH_686 =  float(config["ph"]["PH_686"])


# reading of sensor without pressure applied
P_OFS = float(config["pressure"]["P_OFS"])


i2c = SMBus(1)  # Create a new I2C bus

def _crc(data):
    crc = 0
    for byte in data:
        crc ^= byte
        for _ in range(8):
            if crc & 0x80:
                crc <<= 1
                crc ^= 0x131
            else:
                crc <<= 1
    return crc

def twist(x):
    return struct.unpack('>I', struct.pack('<I', x))[0]

def twist_uint16(x):
    return struct.unpack('>H', struct.pack('<H', x))[0]

def read_uint32(i2c_addr, reg_address):
    data = i2c.read_i2c_block_data(i2c_addr, reg_address, 4)
    return struct.unpack('<I', bytearray(data))[0]

def read_uint16(i2c_addr, reg_address):
    data = i2c.read_i2c_block_data(i2c_addr, reg_address, 2)
    return struct.unpack('<H', bytearray(data))[0]

def write_uint32(i2c_addr, reg_address, value):
    data = struct.pack('<I', value)
    i2c.write_i2c_block_data(i2c_addr, reg_address, list(data))

def ec_adc_to_ec(adcval):
    # f(x) = m*x+t
    # m=dy/dx
    m = (ec_adc_390R - ec_adc_1k)/(EC_390R - EC_1K)
    # t=f(x)-m*x
    t = ec_adc_1k - m * EC_1K
    # x = (f(x)-t) / m
    ec = (adcval - t) / m
    # print("{:f} {:f} {:f}".format(m, t, ec))
    return ec

def ec_temp_compensate(ec, temp):
    # EC25 = EC/(1+a(T-25))
    return ec / (1 + ec_alpha * (temp - 25.0))

def ph_adc_to_ph(adcval):
    # f(x)=m*x+t
    m = (PH_686 - PH_401) / (6.86 - 4.01)
    # t=f(x)-m*x
    t = PH_401 - m * 4.01
    # x=(f(x)-t)/m
    ph = (float(adcval) - t) / m
    return ph


def ph_read():
    config_byte = 0x1c
    if ph_gain==2:
        g=1
    elif ph_gain==4:
        g=2
    elif ph_gain==8:
        g=3
    else:
        pass # illegal value TODO

    i2c.write_byte(i2c_ph, config_byte)

    time.sleep(0.5)

    # format: SSSSSSSD | DDDDDDDD | DDDDDDDD | CCCCCCCC
    unsigned = twist(read_uint32(i2c_ph, config_byte))

    # remove config byte
    # after: 000000000 | SSSSSSSD | DDDDDDDD | DDDDDDDD
    unsigned >>= 8


    # extend sign
    # after: SSSSSSSSS | SSSSSSSD | DDDDDDDD | DDDDDDDD
    if unsigned & 0x00800000:
        unsigned |= 0xff000000

    # unsigned to signed
    signed = struct.unpack('<i', struct.pack('<I', unsigned))[0]

#    print(str(signed))
#    print("voltage: {:f}".format(voltage))
    ph = ph_adc_to_ph(signed)
    # print(signed)
    # print("{:08x}".format(unsigned))
    return (signed, ph)

def ec_read_akku():
    return read_uint32(i2c_ec, 0x00)

def ec_write_akku(value):
    write_uint32(i2c_ec, 0x00, value)

def ec_read_adcval():
    return read_uint16(i2c_ec, 0x04)

def ec_dds(enabled):
    data = [0x80 if not enabled else 0x00]
    i2c.write_i2c_block_data(i2c_ec, 0x04, data)


def temp_read():
    # Read 1-wire Slave file
    file = open('/sys/bus/w1/devices/'+ds18b20+'/w1_slave')
    filecontent = file.read()
    file.close()
 
    # Read and convert temperature
    stringvalue = filecontent.split("\n")[1].split(" ")[9]
    return float(stringvalue[2:]) / 1000

def ec_read(temp):
    ec_dds(True)
    time.sleep(0.5)

    sum = 0
    for i in range(0,256):
        sum += ec_read_adcval()
        time.sleep(0.01)

    adcval = float(sum) / 255.0

    ec_dds(False)
    # print('0x{:04X}'.format(adcval))
    #print("temp:"+str(temp))
    ec = ec_adc_to_ec(adcval)
    #print("ec:"+str(ec))
    ec = ec_temp_compensate(ec, temp)
    #print("ec:"+str(ec))
    return (adcval, ec)
    

def pressure_read():
    sum = 0
    for i in range(0,32):
        sum += twist_uint16(read_uint16(i2c_pressure, 0x04))
        time.sleep(0.01)
    raw = sum / 32
    return raw

def ht_read_reg(reg):
    valid = False
    while True:
        data = i2c.read_i2c_block_data(i2c_ht, reg, 3)
        time.sleep(0.1)
        crc = data[2]
        if _crc(data[:2]) != crc:
            print(str((data)))
            print("crc error reading function 0x{:02x} ({:02x} vs {:02x}) . Trying again".format(reg, _crc(data[:2]), crc))
            time.sleep(1.0)
            continue
        return data


def xht_read():
    rh = ht_read_reg(0xe5)
    humidity = (float(rh[0] * 256 + rh[1]) * 125.0 / 65536.0) - 6.0

    temp = ht_read_reg(0xe3)
    cTemp = (float(temp[0] * 256.0 + temp[1]) * 175.72 / 65536.0) - 46.85

    return (humidity, cTemp)
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
